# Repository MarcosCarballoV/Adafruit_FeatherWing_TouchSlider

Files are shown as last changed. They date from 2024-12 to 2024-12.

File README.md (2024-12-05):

# Adafruit FeatherWing TouchSlider - CAP1208 and NeoPixels




## Overview
FeatherWing TouchSlider is an expansion board for the Adafruit ESP32 Feather V2 featuring the CAP1208 chip with 8 touch pads arranged as a slider. Each pad includes a NeoPixel for visual feedback, perfect for interactive interfaces and dynamic effects.

<p align="center">
  Render_Top
  <br>
  <em>FeatherWing TouchSlider - Render Top</em>
</p>

<p align="center">
  Render_Bot
  <br>
  <em>FeatherWing TouchSlider - Render Bot</em>
</p>

## Supported Modules  

This FeatherWing is designed for the **[Adafruit ESP32 Feather V2](https://www.adafruit.com/product/5400)**, which can be purchased from Adafruit's website along with other Wing modules. It stands out as one of the best development boards due to its easy LiPo battery integration and the ability to stack various pre-designed boards.  

<p align="center">
  Feather_V2
  <br>
  <em>Adafruit ESP32 Feather V2</em>
</p>

## Examples

## Features  

The module integrates the following electronic components:  
- **[CAP1208](https://ww1.microchip.com/downloads/en/DeviceDoc/00001570C.pdf)**: An 8-channel capacitive touch sensor controller with programmable sensitivity, designed for touch sensor applications.  
- **[SK6812MINI-E](https://cdn-shop.adafruit.com/product-files/4960/4960_SK6812MINI-E_REV02_EN.pdf)**: 8 NeoPixels, ideal for not interfering with sliding gestures due to their compact design.  

Communication is handled via I2C, using **GPIO22** and **GPIO20** by default on the ESP32.

<p align="center">
  Feather_V2_PinOut
  <br>
  <em>Adafruit ESP32 Feather V2 - PinOut</em>
</p>

A **RESET button** is included, and a jumper will be added soon to allow selection between RESET or a GPIO pin for use as an interrupt.  

The NeoPixels are powered automatically via USB or the LiPo battery on **VBAT**:  
- **USB power**: 4.3V  
- **LiPo battery**: Voltage ranges from 4.2V to 3.5V depending on the battery charge.  

The manufacturer of the **SK6812MINI-E** specifies an operating voltage of **3.7V to 5.5V**. Therefore, it is recommended not to use a battery discharged below 3.7V, as the colors may become inaccurate.  

<p align="center">
  SK6812MINI-E_Data
  <br>
  <em>SK6812MINI-E - Electrical Parameters</em>
</p>

## Why This Module

Currently, there is no FeatherWing with touch functionalities. This module not only integrates a capacitive touch sensor but also offers a control tool in the form of a slider. Combined with NeoPixels, it enables various interactive experiences and custom feedback through the slider.  

While Adafruit offers different breakout boards, they require jumper wires or I2C cables for connection. Some examples include:  
- **[Adafruit 12-Key Capacitive Touch Sensor Gator Breakout - MPR121](https://www.adafruit.com/product/4830)**  
- **[Adafruit 12-Key Capacitive Touch Sensor Breakout - MPR121](https://www.adafruit.com/product/1982)**  
- **[Adafruit 8-Key Capacitive Touch Sensor Breakout - CAP1188](https://www.adafruit.com/product/1602)**  
- **[Adafruit 5-Pad Capacitive Touch Sensor Breakout - AT42QT1070](https://www.adafruit.com/product/1362)**  

The last two breakout boards include green LEDs to indicate touch detection.  

This FeatherWing provides a more integrated and compact solution for touch-based projects, eliminating the need for additional wiring and enhancing user interaction through built-in NeoPixels.  

### Advantages  

- **Integrated Design**: Combines touch sensing and visual feedback in a single FeatherWing, reducing the need for external wiring.  
- **Slider Functionality**: Offers an intuitive control method for various applications, from UI navigation to custom input controls.  
- **NeoPixel Feedback**: Provides vibrant visual cues with customizable animations for enhanced user interaction.  
- **Seamless Feather Integration**: Designed specifically for Adafruit Feather boards, enabling easy stacking and compact builds.  
- **Power Flexibility**: Automatically switches between USB and LiPo battery power, ensuring consistent NeoPixel performance.  

## Authors

- [@MarcosCarballoV](https://github.com/MarcosCarballoV)

## Setup Instructions

The steps to install this library depend on the IDE you are using. PlatformIO is recommended, but the library can also be used with the plain Arduino IDE.

### PlatformIO (Recommended)

1. **Add the Library:**
   - Open the `platformio.ini` file in your project.
   - Add the following line to include the TouchSlider and CAP1208 library:
     ```ini
     lib_deps =
       https://github.com/MarcosCarballoV/Adafruit_FeatherWing_TouchSlider/Library
     ```

2. **Include the Library in Your Code:**
   - In your main `.cpp` or `.ino` file, include the TouchSlider and CAP1208 library:
     ```cpp
     #include <TouchSlider.h>
     #include <CAP1208.h>
     ```

3. **Upload Your Code:**
   - Write your code using the TouchSlider and CAP1208 library.
   - Connect your ESP32 board to your computer.
   - Click the upload button in PlatformIO to compile and upload your code to the board.

### Arduino IDE

1. **Install the TouchSlider Library:**
   - Download the TouchSlider and CAP1208 library from the [GitHub repository](https://github.com/MarcosCarballoV/Adafruit_FeatherWing_TouchSlider/Library).
   - Open the Arduino IDE.
   - Go to `Sketch` > `Include Library` > `Add .ZIP Library...`.
   - Select the downloaded TouchSlider library ZIP file to install it.

2. **Include the Library in Your Code:**
   - In your `.ino` file, include the TouchSlider and CAP1208 library:
     ```cpp
     #include <TouchSlider.h>
     #include <CAP1208.h>
     ```

3. **Upload Your Code:**
   - Write your code using the TouchSlider and CAP1208 library.
   - Connect your ESP32 board to your computer.
   - Select the correct board and port from `Tools` > `Board` and `Tools` > `Port`.
   - Click the upload button to compile and upload your code to the board.

## Get Started

### Includes and Definitions
To use this library in your project, you need to include the following headers and set up the touch slider.

### Create Logic/Function for Each Gesture
It is necessary to create a function that will be repeatedly called by a timer configured in the main program.

### Configure the TouchSlider and Start
In your setup, or any other part of the main program that only runs once, use the enable/disable functions to configure the features of this library, such as printing messages or using touch buttons. After configuring, start the continuous reading of the touch slider with `touchSlider.start();`. This reading occurs every 50ms by default but can be changed within the library.

### Implement Rest of Your Code
The updateTouchSlider() function will be called every SLIDER_INTERVAL (In this example, 200 ms), independently of the rest of the code

## Schematics  

The schematics for the Adafruit FeatherWing TouchSlider provide a detailed overview of the connections between the CAP1208, NeoPixels, and the ESP32 Feather V2. They include the I2C communication lines, power management, and the RESET button configuration.  

[**View Schematics**](link_to_schematics.pdf)  

## Gerber Files  

The Gerber files for the FeatherWing TouchSlider are available for download, enabling easy fabrication of the PCB. These files include all necessary layers, such as copper, solder mask, and silkscreen, for manufacturing.  

[**Download Gerber Files**](link_to_gerber.zip)

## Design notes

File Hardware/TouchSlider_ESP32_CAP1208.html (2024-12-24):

Altium customize

# Board Information Report

Date: | | 22/11/2024
Time: | | 06:44:57 p. m.
Elapsed Time: | | 00:00:00
Filename: | | D:\Documents\AD24 - Proyects\TouchSliders_ESP32_CAP1208\TouchSlider_ESP32_CAP1208.PcbDoc
Units: | | mmmils

## Contents

Contents

Board Specification

General

Routing

Routing Information

Layer Information

Layer Information

Other

Via Solder Mask

Track Width

Net Via Size

## Board Specification

General
Board Size | 2000mils x 900mils
Components on board | 26

Back to top

## Routing

Routing Information
Routing completion | 100.00%
Connections | 74
Connections routed | 74
Connections remaining | 0

Back to top

## Layer Information

Layer | Arcs | Pads | Vias | Tracks | Texts | Fills | Regions | ComponentBodies
Top Layer | 135 | 8 | 0 | 623 | 0 | 0 | 2 | 0
Bottom Layer | 138 | 83 | 0 | 1018 | 0 | 0 | 12 | 0
Mechanical 1 | 1 | 0 | 0 | 2 | 1 | 0 | 0 | 19
Board Shape | 0 | 0 | 0 | 40 | 0 | 0 | 0 | 0
Board | 0 | 0 | 0 | 0 | 0 | 0 | 0 | 0
Top Assembly | 1 | 0 | 0 | 4 | 0 | 0 | 0 | 0
Bottom Assembly | 3 | 0 | 0 | 113 | 13 | 0 | 5 | 2
Multi-Layer | 0 | 34 | 47 | 0 | 0 | 0 | 9 | 0
Top Paste | 0 | 0 | 0 | 0 | 0 | 0 | 0 | 0
Top Overlay | 0 | 0 | 0 | 7 | 4 | 0 | 0 | 0
Top Solder | 0 | 0 | 0 | 0 | 0 | 0 | 0 | 0
Bottom Solder | 0 | 0 | 0 | 0 | 0 | 0 | 0 | 0
Bottom Overlay | 4 | 0 | 0 | 64 | 48 | 0 | 1 | 0
Bottom Paste | 0 | 0 | 0 | 0 | 0 | 0 | 0 | 0
Drill Guide | 0 | 0 | 0 | 0 | 0 | 0 | 0 | 0
Keep-Out Layer | 0 | 0 | 0 | 0 | 0 | 0 | 0 | 0
Drill Drawing | 0 | 0 | 0 | 0 | 0 | 0 | 0 | 0
Total | 282 | 125 | 47 | 1871 | 66 | 0 | 29 | 21

Back to top

## Other

Via Solder Mask | Count
| Top Solder Mask | Bottom Solder Mask
0mils | 0 | 21
1mils | 26 | 26
4mils | 21 | 0
Total | 47 | 47

Back to top

Track Width | Count
3.937mils | 64
5mils | 1456
5.906mils | 6
6mils | 48
8mils | 35
10mils | 262
Total | 1871

Back to top

Net Via Size | Count
27.559mils | 28
Total | 28

Back to top

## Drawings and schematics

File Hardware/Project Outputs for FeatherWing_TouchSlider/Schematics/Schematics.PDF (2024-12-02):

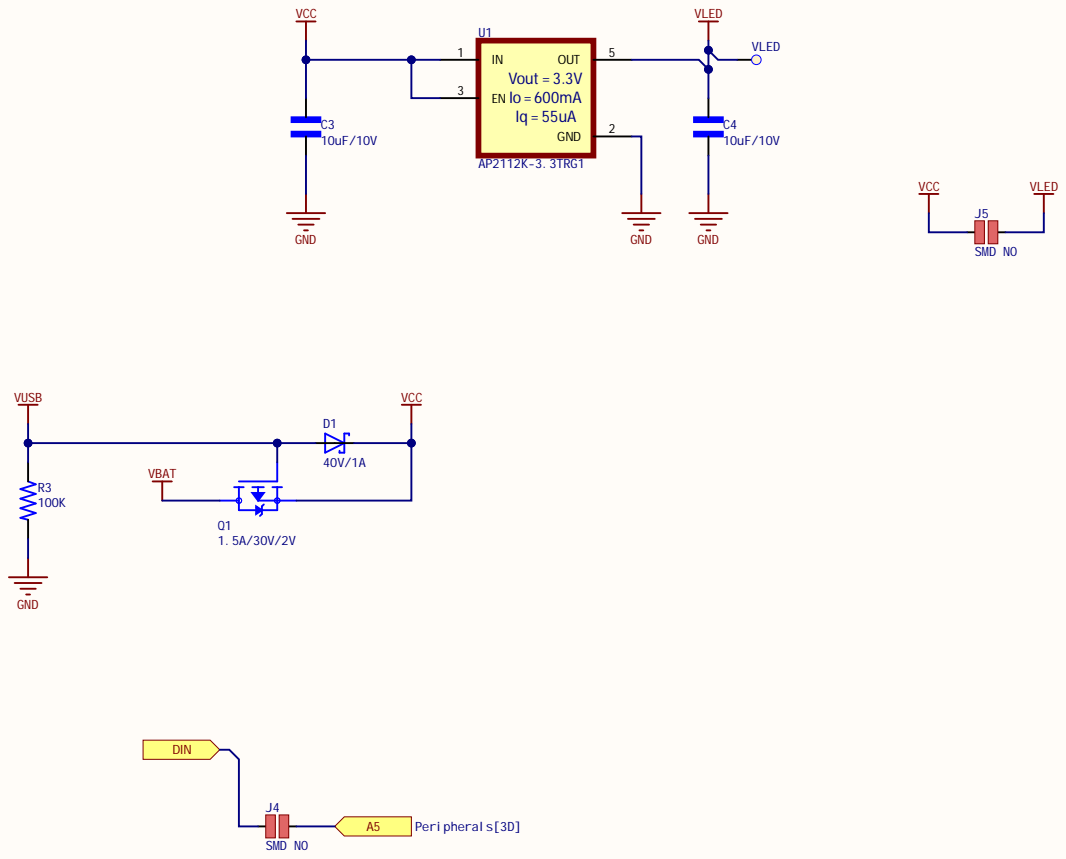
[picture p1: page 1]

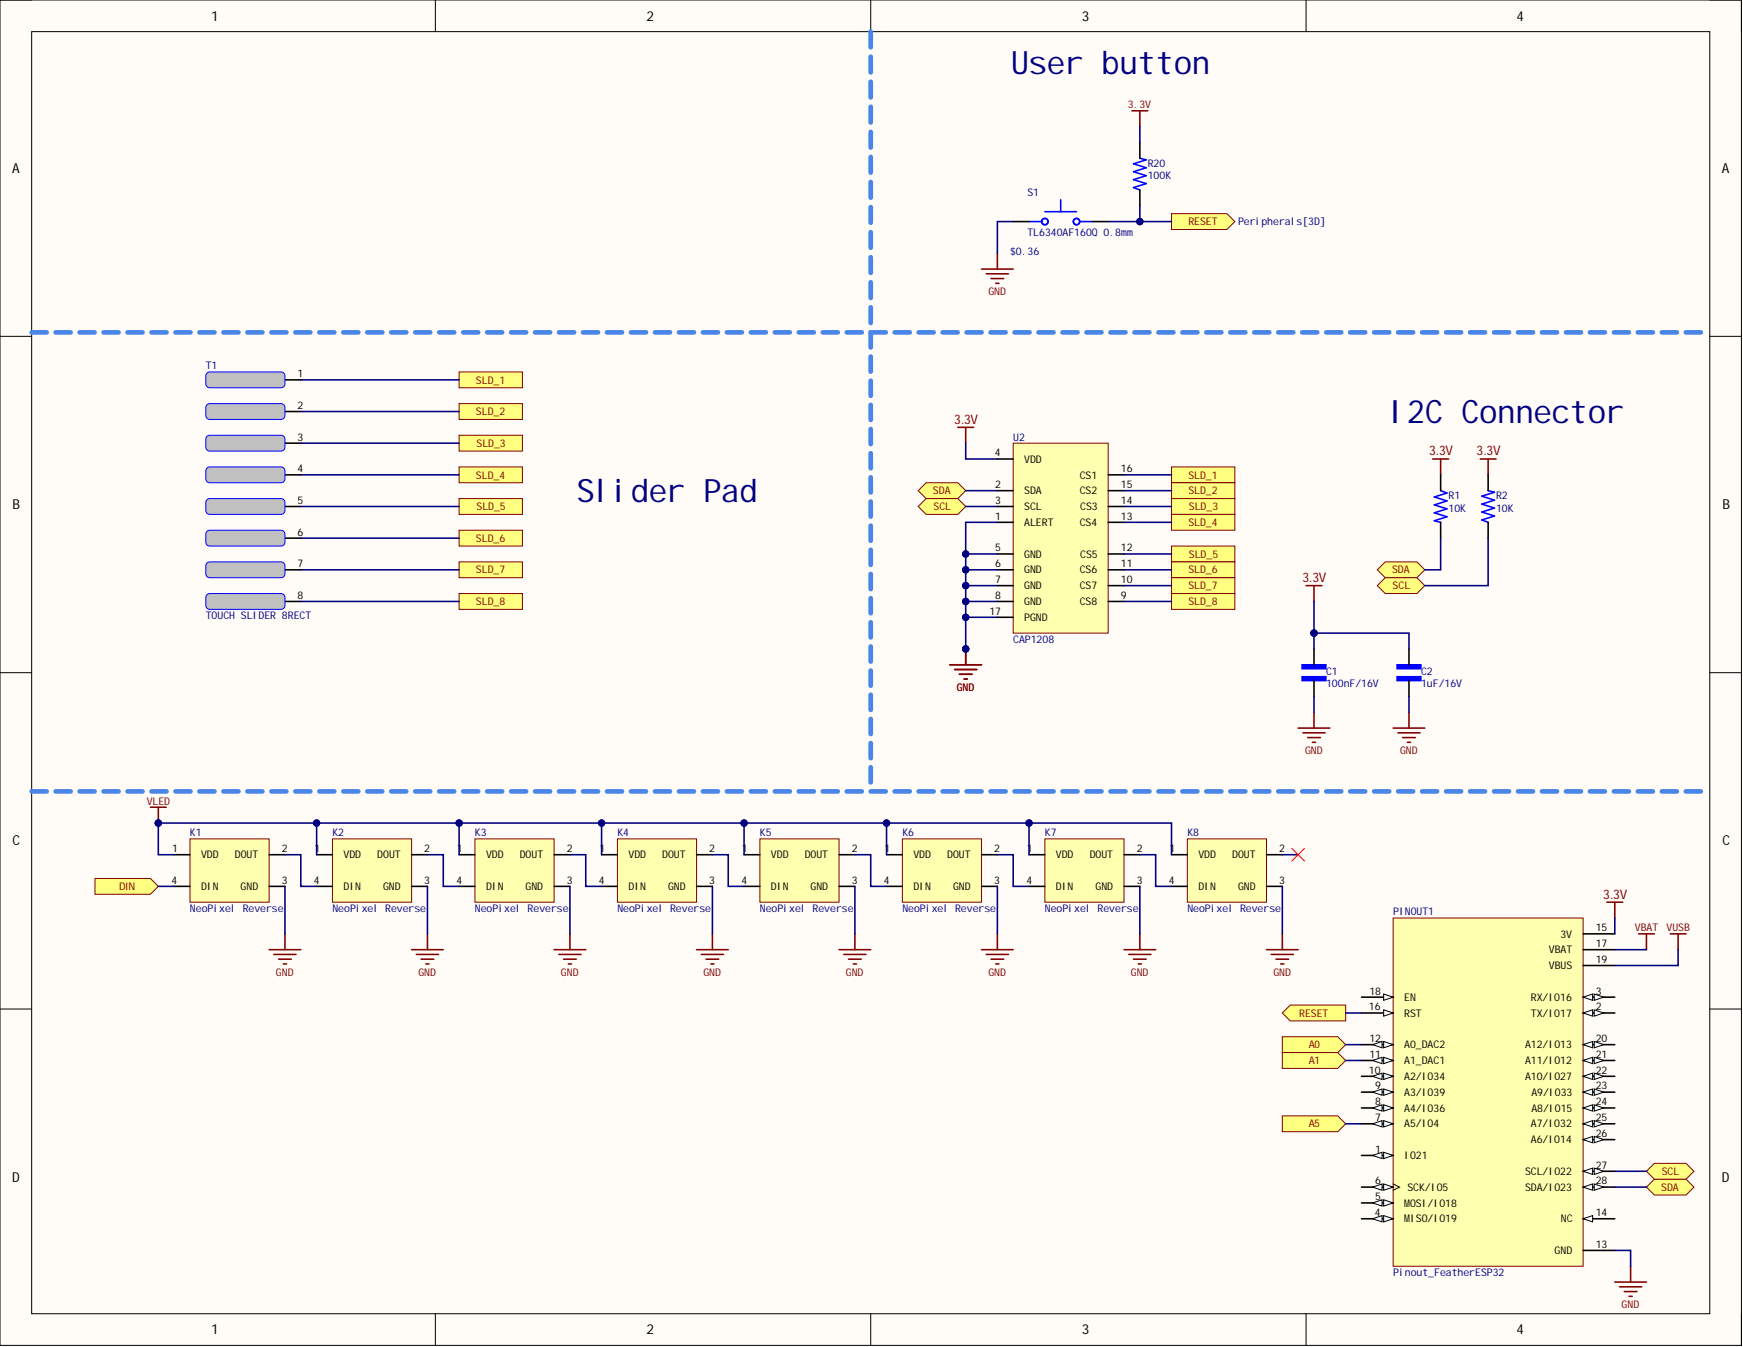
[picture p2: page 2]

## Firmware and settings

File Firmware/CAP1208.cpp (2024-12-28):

#include "CAP1208.h"

/**
 * @brief Constructor for the TouchSlider class.
 *
 * @param addr The address of the CAP1208 sensor.
 */
CAP1208::CAP1208(byte addr) {
  _deviceAddress = addr;
}

/**
 * @brief Initialize the CAP1208 sensor.
 *
 * @param wirePort The Wire port to use for communication.
 * @param deviceAddress The address of the CAP1208 sensor.
 *
 * @return true if the sensor is initialized successfully.
 */
bool CAP1208::begin(TwoWire &wirePort, uint8_t deviceAddress) {
  // Set device address and wire port to private variable
  _deviceAddress = deviceAddress;
  _i2cPort = &wirePort;

  if (isConnected() == false) {
    log_e("CAP1208 not connected");
    return false;
  }

  // Read PROD_ID register
  byte prodIDValue = readRegister(PRODUCT_ID);
  // PROD_ID should always be 0x6D
  if (prodIDValue != PROD_ID_VALUE) {
    log_e("Product ID not correct, 0x%x", prodIDValue);
    return false;
  }

  return true;  // Success
}

/**
 *  @brief Check if the sensor is connected
 *
 *  @return true if the sensor is connected
 */
bool CAP1208::isConnected() {
  for (byte i = 0; i < 5; i++) {
    /* After inspecting with logic analyzer, the device fails
        to connect for unknown reasons. The device typically connects
        after two calls. We included a for loop to allow for
        multiple calls to the device.
    */
    _i2cPort->beginTransmission((uint8_t)_deviceAddress);
    if (_i2cPort->endTransmission() == 0)
      return (true);  // Sensor did not ACK
  }

  return (false);
}

/**
 * @brief Checks the main control register.
 * @note See datasheet on Main Control Register
 */
void CAP1208::checkMainControl() {
  MAIN_CONTROL_REG reg;
  reg.MAIN_CONTROL_COMBINED = readRegister(MAIN_CTRL_REG);
}

/**
 * @brief Checks the general status register
 * @note See datasheet on General Status Register
 */
void CAP1208::checkStatus() {
  GENERAL_STATUS_REG reg;
  reg.GENERAL_STATUS_COMBINED = readRegister(GEN_STATUS);
}

/**
 * @brief Clears the interrupt pin
 */
void CAP1208::clearInterrupt() {
  MAIN_CONTROL_REG reg;
  reg.MAIN_CONTROL_COMBINED = readRegister(MAIN_CTRL_REG);
  reg.MAIN_CONTROL_FIELDS.INT = 0x00;
  writeRegister(MAIN_CTRL_REG, reg.MAIN_CONTROL_COMBINED);
}

/**
 * @brief Disables all interrupts
 */
void CAP1208::setInterruptDisabled() {
  INTERRUPT_ENABLE_REG reg;
  reg.INTERRUPT_ENABLE_COMBINED = readRegister(INT_ENABLE);
  reg.INTERRUPT_ENABLE_FIELDS.CS1_INT_EN = 0x00;
  reg.INTERRUPT_ENABLE_FIELDS.CS2_INT_EN = 0x00;
  reg.INTERRUPT_ENABLE_FIELDS.CS3_INT_EN = 0x00;
  reg.INTERRUPT_ENABLE_FIELDS.CS4_INT_EN = 0x00;
  reg.INTERRUPT_ENABLE_FIELDS.CS5_INT_EN = 0x00;
  reg.INTERRUPT_ENABLE_FIELDS.CS6_INT_EN = 0x00;
  reg.INTERRUPT_ENABLE_FIELDS.CS7_INT_EN = 0x00;
  reg.INTERRUPT_ENABLE_FIELDS.CS8_INT_EN = 0x00;
  writeRegister(INT_ENABLE, reg.INTERRUPT_ENABLE_COMBINED);
}

/**
 * @brief Sets all interrupts
 */
void CAP1208::setInterruptEnabled() {
  INTERRUPT_ENABLE_REG reg;
  reg.INTERRUPT_ENABLE_COMBINED = readRegister(INT_ENABLE);
  reg.INTERRUPT_ENABLE_FIELDS.CS1_INT_EN = 0x01;
  reg.INTERRUPT_ENABLE_FIELDS.CS2_INT_EN = 0x01;
  reg.INTERRUPT_ENABLE_FIELDS.CS3_INT_EN = 0x01;
  reg.INTERRUPT_ENABLE_FIELDS.CS4_INT_EN = 0x01;
  reg.INTERRUPT_ENABLE_FIELDS.CS5_INT_EN = 0x01;
  reg.INTERRUPT_ENABLE_FIELDS.CS6_INT_EN = 0x01;
  reg.INTERRUPT_ENABLE_FIELDS.CS7_INT_EN = 0x01;
  reg.INTERRUPT_ENABLE_FIELDS.CS8_INT_EN = 0x01;
  writeRegister(INT_ENABLE, reg.INTERRUPT_ENABLE_COMBINED);
}

/**
 * @brief Checks if interrupts are enabled
 *
 * @return true if interrupts are enabled
 */
bool CAP1208::isInterruptEnabled() {
  INTERRUPT_ENABLE_REG reg;
  reg.INTERRUPT_ENABLE_COMBINED = readRegister(INT_ENABLE);
  if (reg.INTERRUPT_ENABLE_FIELDS.CS1_INT_EN == 0x01 && reg.INTERRUPT_ENABLE_FIELDS.CS2_INT_EN == 0x01 && reg.INTERRUPT_ENABLE_FIELDS.CS3_INT_EN == 0x01) {
    return true;
  }
  return false;
}

/**
 * @brief Sets the sensitivity
 * 
 * @param  sensitivity: Sensitivity value, SENSITIVITY_128X to SENSITIVITY_1X (Most sensitive to least sensitive)
 * @note See datasheet on Sensitivity, default is SENSITIVITY_32X
 */
void CAP1208::setSensitivity(uint8_t sensitivity) {
  SENSITIVITY_CONTROL_REG reg;
  reg.SENSITIVITY_CONTROL_COMBINED = readRegister(SENSITIVITY);
  if (sensitivity == SENSITIVITY_128X) {
    reg.SENSITIVITY_CONTROL_FIELDS.DELTA_SENSE = SENSITIVITY_128X;
  } else if (sensitivity == SENSITIVITY_64X) {
    reg.SENSITIVITY_CONTROL_FIELDS.DELTA_SENSE = SENSITIVITY_64X;
  } else if (sensitivity == SENSITIVITY_32X) {
    reg.SENSITIVITY_CONTROL_FIELDS.DELTA_SENSE = SENSITIVITY_32X;
  } else if (sensitivity == SENSITIVITY_16X) {
    reg.SENSITIVITY_CONTROL_FIELDS.DELTA_SENSE = SENSITIVITY_16X;
  } else if (sensitivity == SENSITIVITY_8X) {
    reg.SENSITIVITY_CONTROL_FIELDS.DELTA_SENSE = SENSITIVITY_8X;
  } else if (sensitivity == SENSITIVITY_4X) {
    reg.SENSITIVITY_CONTROL_FIELDS.DELTA_SENSE = SENSITIVITY_4X;
  } else if (sensitivity == SENSITIVITY_1X) {
    reg.SENSITIVITY_CONTROL_FIELDS.DELTA_SENSE = SENSITIVITY_1X;
  } else {
    // Default case: calibrated for CAP1208 touch sensor
    reg.SENSITIVITY_CONTROL_FIELDS.DELTA_SENSE = SENSITIVITY_2X;
  }
  writeRegister(SENSITIVITY, reg.SENSITIVITY_CONTROL_COMBINED);
}

/**
 * @brief Gets the sensitivity
 * 
 * @return Sensitivity value, SENSITIVITY_128X to SENSITIVITY_1X (Most sensitive to least sensitive)
 */
uint8_t CAP1208::getSensitivity() {
  SENSITIVITY_CONTROL_REG reg;
  reg.SENSITIVITY_CONTROL_COMBINED = readRegister(SENSITIVITY);
  uint16_t sensitivity = reg.SENSITIVITY_CONTROL_FIELDS.DELTA_SENSE;
  if (sensitivity == SENSITIVITY_128X) {
    return 128;
  } else if (sensitivity == SENSITIVITY_64X) {
    return 64;
  } else if (sensitivity == SENSITIVITY_32X) {
    return 32;
  } else if (sensitivity == SENSITIVITY_16X) {
    return 16;
  } else if (sensitivity == SENSITIVITY_8X) {
    return 8;
  } else if (sensitivity == SENSITIVITY_4X) {
    return 4;
  } else if (sensitivity == SENSITIVITY_2X) {
    return 2;
  } else if (sensitivity == SENSITIVITY_1X) {
    return 1;
  } else {
    // Error - no possible register value (pg. 25)
    return 0;
  }
}

/**
 * @brief Checks if the sensor is touched
 * @note See datasheet on General Status Register
 * @retval true if the sensor is touched
 */
bool CAP1208::isTouched() {
  GENERAL_STATUS_REG reg;
  reg.GENERAL_STATUS_COMBINED = readRegister(GEN_STATUS);

  // Touch detected
  if (reg.GENERAL_STATUS_FIELDS.TOUCH == ON) {
    clearInterrupt();
    return true;
  }
  return false;
}

/**
 * @brief Reads the product ID
 * @note  See datasheet on Product ID
 * @retval The product ID
 */
uint8_t CAP1208::readID() {
  uint8_t id;

  readRegisters(PRODUCT_ID, &id, 1);

  return id;
}

/**
 * @brief Sets the sensor to standby mode
 */
void CAP1208::StandbyMode() {
  MAIN_CONTROL_REG reg;
  reg.MAIN_CONTROL_COMBINED = readRegister(MAIN_CTRL_REG);
  reg.MAIN_CONTROL_FIELDS.STBY = true;
  writeRegister(MAIN_CTRL_REG, reg.MAIN_CONTROL_COMBINED);
}
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

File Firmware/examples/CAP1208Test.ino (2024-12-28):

#include <Adafruit_NeoPixel.h>  // NeoPixel library
#include <Arduino.h>            // Arduino library
#include <Wire.h>               // I2C library
#include "CAP1208.h"      // Capacitive sensor library
#include "Logger.h"       // Logger library
#include "TouchSlider.h"  // Touch slider library

// Pins designed for NeoPixels, edit according to your setup
#define PIN 4               // Pin connected to NeoPixels
#define NUMPIXELS 8         // NeoPixel ring size
#define DELAYVAL 80         // Time (in milliseconds) to pause between pixels
#define MAX_BRIGHTNESS 50   // The maximum brightness of the LED (In this example we recommend multiple of STEP_BRIGHTNESS)
#define STEP_BRIGHTNESS 10  // The step brightness of the LED

// Array to store the state of the pads
bool PadsTouched[8] = {0, 0, 0, 0, 0, 0, 0, 0};

// Objects
Adafruit_NeoPixel pixels(NUMPIXELS, PIN, NEO_GRB + NEO_KHZ800);  // NeoPixel object
CAP1208 CAP1208_Sensor;                                          // CAP1208 object
TouchSlider Slider(&CAP1208_Sensor);                             // TouchSlider object

void setup() {
  Wire.begin();          // Join I2C bus
  Serial.begin(115200);  // Start serial for output

  log_i("Starting up with NeoPixel strip...");
  delay(100);
  pixels.begin();  // INITIALIZE NeoPixel strip object (REQUIRED)
  pixels.clear();  // Set all pixel colors to 'off'

  log_i("Starting up with CAP1208 sensor...");
  CAP1208_Sensor.begin();                          // Initialize the CAP1208 sensor
  CAP1208_Sensor.ConfigureMultiTouch(4);           // Configure MultiTouch to 4 pads
  CAP1208_Sensor.setSensitivity(SENSITIVITY_32X);  // Set sensitivity to 32x on startup (change this variable to change sensitivity according to your needs)

  Slider.start();  // Start the touch slider
}

void loop() {
  static uint8_t _BRIGHTNESS = MAX_BRIGHTNESS;  // The brightness of the LED
  int8_t _SaveStatusFine = 0;                   // The status of the swipe, reset every loop

  Slider.getSliderTouched(PadsTouched, sizeof(PadsTouched));  // Get the state of the pads

  pixels.clear();                                      // Clear the strip
  for (uint8_t i = 0; i < sizeof(PadsTouched); i++) {  // For each pad
    if (PadsTouched[i]) {                              // If the pad is touched
      pixels.setPixelColor(i, pixels.Color(_BRIGHTNESS / 2, _BRIGHTNESS / 2, _BRIGHTNESS));  // Set pixel's color
    }
  }
  pixels.show();  // Send the updated pixel colors to the hardware

  _SaveStatusFine = Slider.getSwipeStatusFine();  // Get the status of the swipe

  if (_SaveStatusFine != 0) {  // If the status of the swipe is not 0
    log_i("The swipe status fine is %d", _SaveStatusFine);
    if (_SaveStatusFine > 0) {            // If the swipe status fine is positive
      if (_BRIGHTNESS != MAX_BRIGHTNESS)  // If the brightness is not MAX_BRIGHTNESS
        _BRIGHTNESS += STEP_BRIGHTNESS;   // Add 10 to the brightness
    } else {
      if (_BRIGHTNESS != 0)              // If the brightness is not 0
        _BRIGHTNESS -= STEP_BRIGHTNESS;  // Subtract 10 from the brightness
    }

    if (_BRIGHTNESS > MAX_BRIGHTNESS) {  // If the brightness is greater than MAX_BRIGHTNESS
      _BRIGHTNESS = MAX_BRIGHTNESS;      // Set the brightness to MAX_BRIGHTNESS
    } else if (_BRIGHTNESS < 0) {        // If the brightness is less than 0
      _BRIGHTNESS = 0;                   // Set the brightness to 0
    }
    log_i("The brightness is %d", _BRIGHTNESS);
  }
}

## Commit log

2024-12-02 Add a Outputs Files
    [TouchSlider_ESP32_CAP1208.GBL, TouchSlider_ESP32_CAP1208.GBO, TouchSlider_ESP32_CAP1208.GBP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]
2024-12-24 Order - add Firmware and Hardware Folders
    [Peripherals.SchDoc, Power_Supplies.SchDoc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]
